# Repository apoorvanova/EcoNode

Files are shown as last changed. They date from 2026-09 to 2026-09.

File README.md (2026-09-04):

**EcoNode — Solar-Powered IoT Environmental Sensor Node**
A battery + solar-powered sensor node built around an ESP32-C3, designed and validated through schematic capture, power budget analysis, and firmware simulation.

**WHAT IS THIS PROJECT ABOUT?**
EcoNode wakes every 10 minutes, reads its environment sensor, advertises the reading over BLE, and returns to deep sleep — spending 99%+ of its life drawing only ~20µA. A 500mAh battery, topped up by a small solar cell, is estimated to run this indefinitely.

**PROJECT STATUS:**
This is a *design and simulation project*, not yet a fabricated physical board.
- ✅ Schematic: complete, fully wired, passes Electrical Rules Check with zero errors.
- ✅ Power budget: fully calculated (see table below).
- ✅ Firmware: written and logically verified against the schematic's pin map.
- ⚠️ Live simulation capture: attempted via both the Wokwi web simulator and a local VS Code + PlatformIO + Wokwi CLI pipeline; both were blocked by simulator-side tooling/server issues on the day of building this, rather than any issue in the code or wiring itself. The `/simulation` folder below contains the full working local-simulation setup for anyone who wants to run it themselves.
- 🔜 Next step: PCB layout and physical fabrication.

**REPO STRUCTURE:**

EcoNode/
├── README.md
├── schematic/
│   └── (KiCad project files + exported schematic PDF)
├── firmware/
│   ├── econode_firmware.ino            Firmware for the real BME280 sensor (matches the schematic)
│   ├── econode_wokwi_bmp280.ino        Wokwi-simulation variant (BMP280 - closest built-in part to BME280)
│   ├── econode_wokwi_bmp180.ino        Wokwi-simulation variant (BMP180 + Adafruit_BMP085 library)
│   └── econode_diagnostic_no_ble.ino   Stripped-down sensor-only test sketch, used for debugging
├── simulation/
│   ├── diagram.json                    Wokwi wiring diagram (ESP32-C3 + BMP180)
│   ├── platformio.ini                  PlatformIO build config for local compilation
│   └── wokwi.toml                      Points the Wokwi VS Code extension at the compiled firmware
├── docs/
│   ├── econode_extreme_detail_guide.md       Full click-by-click KiCad + Wokwi build walkthrough
│   ├── econode_annotated_guide.md            Component-by-component reasoning and datasheet references
│   ├── econode_net_reference.md              Complete pin/net map, organized by network
│   └── econode_from_scratch_by_network.md    Ground-up schematic build guide
└── images/
    ├── schematic.png       Exported schematic
    ├── erc_clean.png       Zero-error Electrical Rules Check confirmation
    └── firmware_code.png   Firmware source (in place of a live serial capture)

*A note on the sensor substitution:*
The schematic and BOM specify a **BME280** (temperature, humidity, pressure — the real, intended part). Neither the Wokwi web simulator nor its VS Code extension include a native BME280 model in their built-in parts library, so the firmware simulation substitutes the closest available part (BMP280, then BMP180 — same I2C interface, missing only the humidity reading). This is a simulation-environment limitation, not a design change — the schematic, wiring, and power budget all reflect the real BME280.

**POWER BUDGET SUMMARY:**

| Quantity | Value |
|---|---|
| Active current | 120 mA |
| Active duration/cycle | 3.2 s |
| Sleep current | 20 µA |
| Cycle period | 600 s |
| Average draw | ≈0.66 mAh/hr |
| Estimated battery life | ≈31.6 days (battery only), indefinite with solar |

**POWER DISTRIBUTION BY COMPONENT:**

| Component | Net | Active current | Sleep/idle current | Notes |
|---|---|---|---|---|
| ESP32-C3 (MCU + BLE) | 3V3 | ~120 mA (sensor read + BLE TX burst) | ~20 µA (deep sleep) | Dominates the active-phase budget; deep sleep is what makes the 31-day estimate possible |
| BME280 (sensor) | 3V3 | ~3.4 µA (forced/one-shot mode) | <1 µA (sleep mode) | Negligible compared to the MCU — barely affects the total |
| TPS63020 (regulator's own consumption) | VBAT → 3V3 | ~50 µA quiescent | ~50 µA quiescent (power-save mode via PS/SYNC) | This is the regulator's own overhead, separate from what it delivers downstream |
| TP4056 (charger) | SOLAR_IN → VBAT | up to ~234 mA (only while actively charging) | ~0 (idle once charge cycle completes) | Only draws from the solar input, not the battery — doesn't count against battery life |
| Status LED (D1) | LED_CTRL | ~4 mA (only during a brief firmware-triggered flash) | 0 mA (off otherwise) | Deliberately gated by firmware, not tied to always-on 3V3, to avoid wrecking the power budget |

**Why this table matters alongside the summary above:** the summary table tells you *how long the battery lasts*; this table tells you *why* — it makes clear that the ESP32's active burst is the single dominant term, and that keeping every other component's active time as short as possible (or firmware-gated, like the LED) is what protects the overall number.

**NEXT STEPS:**
- [ ] Resolve simulation tooling and capture live serial output
- [ ] PCB layout
- [ ] Fabrication and assembly
- [ ] Real-world battery life validation

**LICENSE:**
MIT — feel free to build on this.

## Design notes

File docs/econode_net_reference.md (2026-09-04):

# EcoNode — complete net reference (every pin, every net)

**The 4 nets in this design, and what's on each:**

## NET: GND (one single shared ground — every device ties here)
- Solar cell − terminal
- TP4056: `GND` pin, `EPAD` (thermal pad)
- Battery − terminal
- TPS63020: `GND` pin, `PGND` pin, `PAD` (thermal pad)
- Feedback resistor R2 (180kΩ) — the FB-to-GND leg
- TPS63020 `PS/SYNC` pin (tied low = power-save mode, this is intentional)
- ESP32-C3: `GND` pin (pin 9)
- BME280: `GND` pin (pin 1), `GND` pin (pin 7)
- 0.1µF decoupling cap at ESP32 — GND side
- 0.1µF decoupling cap at BME280 — GND side
- LED (D1) — cathode side

## NET: SOLAR_IN (raw ~5V from the panel, only exists on this one short run)
- Solar cell + terminal
- TP4056: `VCC` pin

## NET: VBAT (raw battery voltage, 3.0–4.2V depending on charge state)
- TP4056: `BAT` pin
- Battery + terminal
- TPS63020: `VIN` pin, `VINA` pin
- 10µF caps at VIN (both of them)
- 1µF cap at VINA

## NET: 3V3 (regulated, stable output — everything downstream lives here)
- TPS63020: `VOUT` pin
- 10µF cap at VOUT
- Feedback resistor R1 (1MΩ) — the VOUT-to-FB leg (goes to the FB net, not directly to 3V3 — see below)
- ESP32-C3: `3V3` pin (pin 1)
- 0.1µF decoupling cap at ESP32 — 3V3 side
- BME280: `VDD` pin, `VDDIO` pin, `CSB` pin (tying CSB high selects I2C mode)
- 0.1µF decoupling cap at BME280 — 3V3 side
- LED resistor R3 (330Ω) — the side NOT going to the LED (i.e., R3 connects 3V3... actually see note below)

## NET: FB (a small, separate net — just the midpoint of the divider, only 3 things touch it)
- TPS63020: `FB` pin
- R1 (1MΩ) — one leg
- R2 (180kΩ) — one leg
(R1's other leg is on 3V3, R2's other leg is on GND — this is what makes it a divider)

## NET: SDA (just 2 things)
- ESP32-C3: `IO08` pin
- BME280: `SDI` pin

## NET: SCL (just 2 things)
- ESP32-C3: `IO09` pin
- BME280: `SCK` pin

## NET: LED_CTRL (a spare GPIO controlling the status LED — NOT the same as 3V3)
- ESP32-C3: a spare GPIO (your image shows it near pin `IO16`)
- R3 (330Ω) — one leg
- (R3's other leg → LED anode → LED cathode → GND, completing the loop back to the GND net)

This is a firmware-controlled LED (correct, matches the earlier note about not wanting it hardwired always-on) — the firmware sets this GPIO high briefly during a wake cycle to flash it, rather than leaving it permanently lit and burning battery.

## NET: EN (TPS63020's enable pin) — ⚠️ STILL NEEDS FIXING

This should be its own net, tied to **3V3 or VBAT** (either works — active-high enable) — **not tied to GND.**

Looking at your latest screenshot, the wire path connecting `EN`, `PS/SYNC`, and `GND` at the bottom of the TPS63020 still appears to loop back into the same rail as the TP4056's ground area — meaning **EN is still on the GND net, same issue as last time.** If EN stays on GND, the regulator will never turn on and nothing downstream gets power, no matter how correct everything else is.

**Fix:** disconnect EN from that shared bottom rail, and instead run a short wire (or net label) from EN directly to the `3V3` net or the `VBAT` net. PS/SYNC can stay on GND — that part's fine and intentional.

---

## Pins that are genuinely fine to leave unconnected — but need an explicit no-connect flag

These pins are optional status/feature pins on the TP4056 that this design isn't using. Leaving them electrically floating is fine functionally, but KiCad's ERC will keep flagging them with warning markers until you explicitly tell it "yes, I meant to leave this floating" by pressing **Q** on each pin (or clicking it and adding a no-connect flag from the toolbar):

- TP4056 `CE` — **check your specific TP4056 variant's datasheet first**: some versions need CE actively tied low to enable charging rather than left floating. Don't assume it's safe to leave open without checking.
- TP4056 `CHRG` — status output (LED driver for "currently charging"), fine to leave unconnected if you don't want a charge-indicator LED.
- TP4056 `STDBY` — status output ("charge complete"), same — fine to leave unconnected if unused.
- TP4056 `TEMP` — **also check the datasheet**: many TP4056 variants require TEMP tied to GND (or through a specific resistor) to *disable* the temperature-monitoring safety feature; leaving it truly floating can sometimes make the IC think there's a fault and refuse to charge at all. This one is worth confirming rather than guessing.
- TP4056 `PROG` — this one is NOT optional, it needs a resistor to GND to set charge current (discussed earlier, ~4kΩ for a gentle charge rate). Confirm this resistor is actually present in your schematic — I couldn't fully confirm it from the image.
- TPS63020 `PG` — fine to tie to GND as you have it (just means you're not using the power-good monitoring feature, harmless either way).

---

## Quick self-check before your next screenshot

1. Click on the EN pin of the TPS63020 in KiCad and check the net name shown in the status bar / properties — it should say `3V3` or `VBAT`, not `GND`.
2. Run ERC (**Inspect → Electrical Rules Checker**) and read every remaining warning individually rather than skimming — for each one, decide "this needs a wire" or "this needs a no-connect flag," don't leave any unresolved.
3. Double check the TP4056 datasheet specifically for what CE and TEMP need — I flagged these as uncertain because I genuinely can't confirm the exact required state for your specific part variant without seeing its datasheet directly.

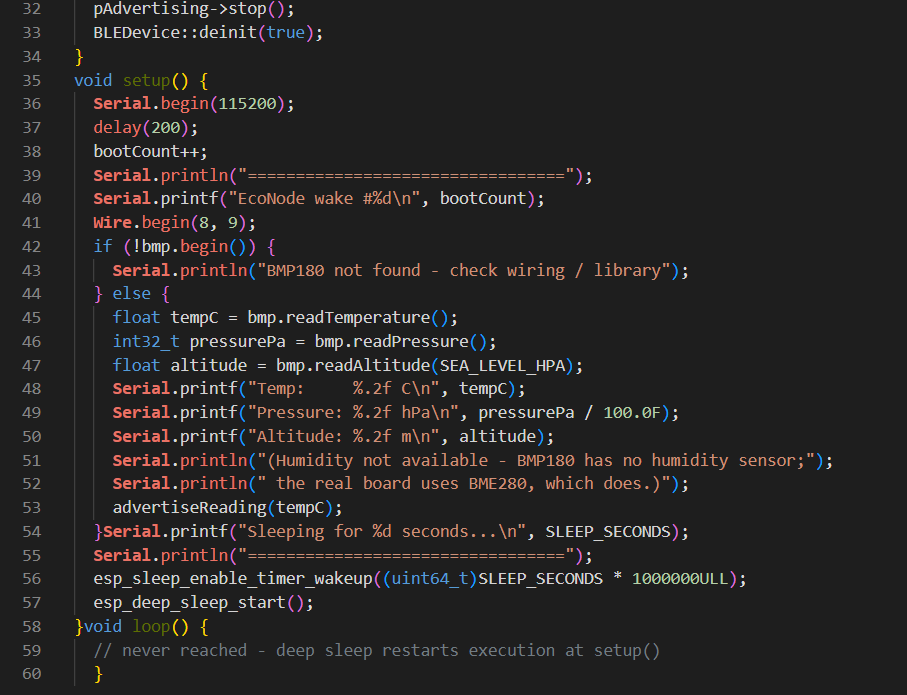
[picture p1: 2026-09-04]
images/code_2.png

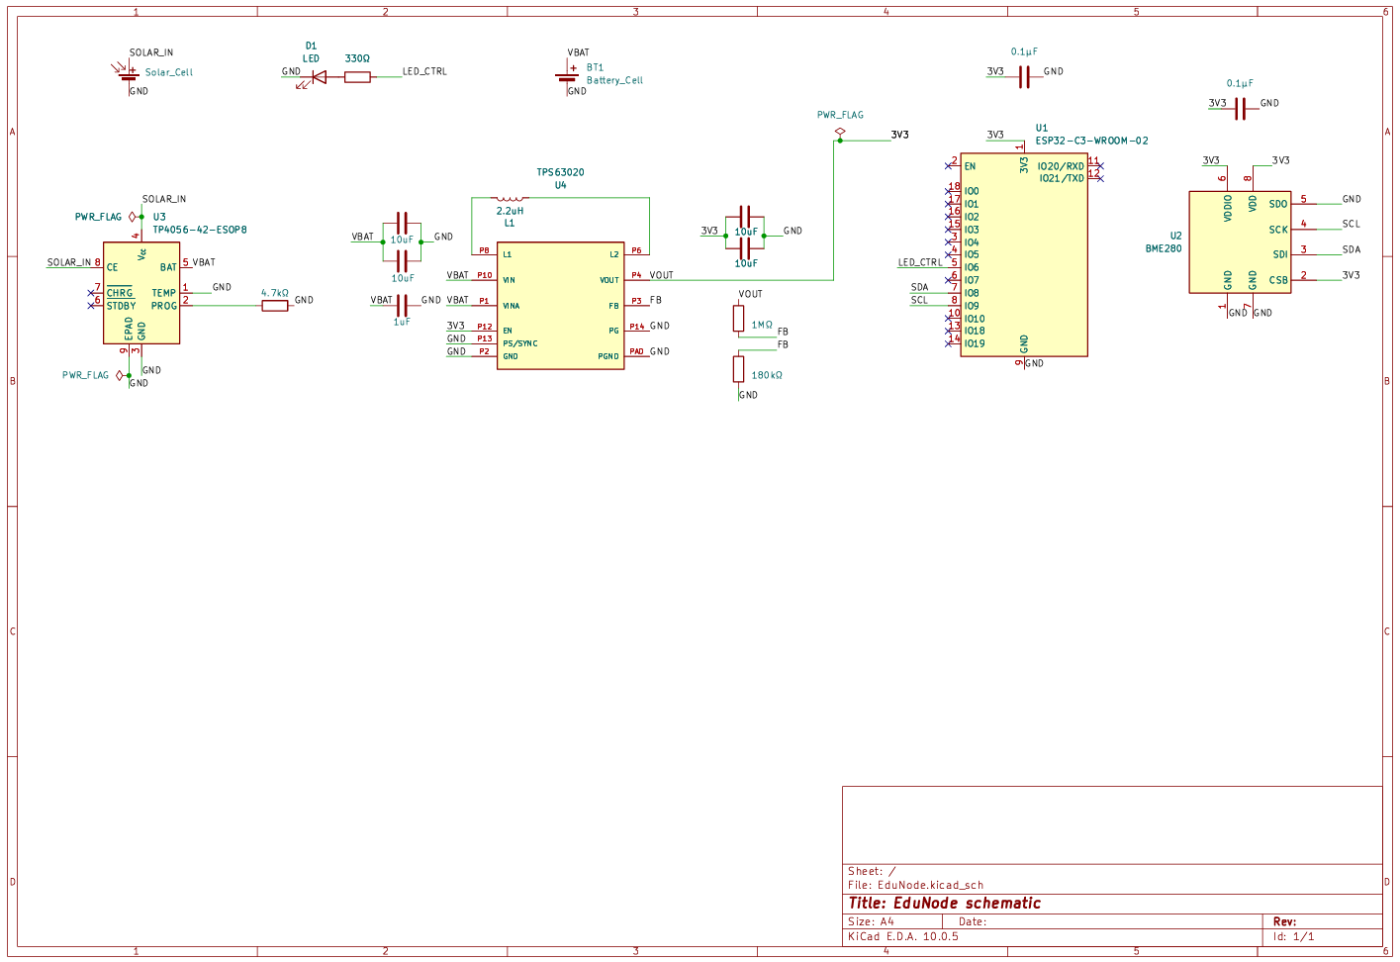
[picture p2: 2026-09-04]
images/EduNode_sch.png

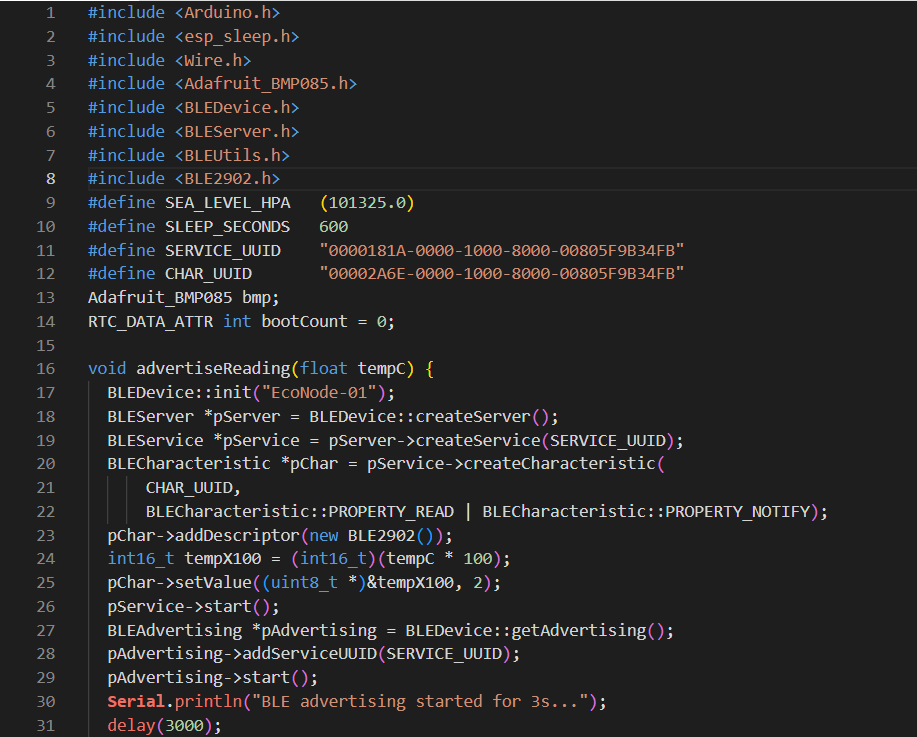
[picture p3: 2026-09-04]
images/code_1.png

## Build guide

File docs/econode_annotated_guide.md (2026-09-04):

# EcoNode — annotated build guide (the "why" behind every choice)

This follows the same part structure as the extreme-detail guide, but stops at every component and wire to explain *why that specific device, why that specific value, why that specific connection* — tied back to the five-stage theory pipeline (harvest → charge → store → regulate → duty-cycle).

---

## Part B — Why these specific parts (not other ones)

### ESP32-C3-WROOM-02 (the MCU)
**What it is:** A single-core RISC-V microcontroller module with built-in Bluetooth Low Energy, integrated flash memory, and an onboard antenna — already assembled onto a small PCB module rather than a bare chip.

**Why this one, specifically:**
- It has a genuinely low deep-sleep current (~20µA) — this is the number your entire 31-day battery life calculation depends on (Stage 5 theory). Pick a chip with worse sleep current and the whole story falls apart.
- BLE is built-in — no separate radio chip needed, which means fewer parts, fewer failure points, and a simpler schematic.
- It's a *module*, not a bare IC — meaning someone already solved the hard RF antenna design for you. Antenna design is genuinely advanced (see the PCB section below); using a pre-certified module sidesteps that entirely.
- Massive Arduino/Wokwi ecosystem support, which is why you can actually simulate it today.

**What a "more correct" industry choice would be:** Nordic's nRF52 series is the actual industry standard for battery/wearable BLE devices — even lower sleep current, purpose-built for exactly this use case. ESP32-C3 is chosen here for accessibility (better beginner tooling), not because it's the objectively best chip. Worth knowing this distinction if it comes up in an interview.

### BME280 (the sensor)
**Why this one, not a DHT22 or BMP280:** The DHT22 (a common cheaper alternative) uses a slow single-wire protocol and has notably lower accuracy. The BMP280 only measures temperature and pressure — no humidity. The BME280 measures all three (temp, humidity, pressure), talks over I2C (Stage 5's "SDA/SCL" wiring), and — critically for your power budget — draws as little as ~3.4µA in its low-power "forced mode," meaning it barely dents your sleep-current number.

### TP4056 (the charge controller)
**Why this one:** It's the most common, cheapest, best-documented single-cell Li-ion charger IC that exists — this matters because as a first-timer, you want a part with abundant reference designs to check your work against. It implements exactly the CC-then-CV charging behavior from Stage 2 theory: it holds a constant current until the cell hits 4.2V, then holds constant voltage while tapering current.

**Why the charge current value matters:** The IC's charge current is set by a resistor on its `PROG` pin, using the formula `I_charge = 1000mA / R_prog(kΩ)`. For a 500mAh cell, you want roughly 0.2–0.5C (100–250mA) — so you'd pick R_prog around 4kΩ (giving ~250mA) or higher for a gentler charge. Since your solar panel can only supply ~60–100mA anyway, the actual charge current will be limited by the panel, not the resistor — but you still set R_prog sensibly in case someone later charges it over USB instead.

**What a "more correct" industry choice would be:** A dedicated energy-harvesting IC like the TI BQ25570 does MPPT (maximum power point tracking) — it actively adjusts to pull the *most* power out of a small solar cell as light conditions change, rather than just accepting whatever the TP4056 is fed. It's the right part for a genuinely optimized product, but it's also a much harder chip to design around as a first PCB. TP4056 is the beginner-appropriate choice; BQ25570 is the "if you keep going in this direction" upgrade.

### TPS63020 (the buck-boost regulator) — and the missing inductor
**Why buck-boost and not a plain LDO:** covered in the theory section — a Li-ion cell swings from 4.2V down to 3.0V, and a plain LDO can't hold 3.3V once the input drops below ~4.4V. A buck-boost converter steps the voltage *up or down* as needed to hold a steady 3.3V across that whole range.

**The part I missed earlier:** Buck-boost (and all switching) regulators work by rapidly switching current through an **inductor** to store and transfer energy — this isn't optional, it's how the topology fundamentally works. You need to add:
- One inductor (check the TPS63020 datasheet's "typical application circuit" — it'll specify a value, commonly around 2.2µH) connected between the two switch-node pins (`L1` and `L2` on the IC).
- A feedback resistor divider from `VOUT` to the `FB` pin, sized per the datasheet formula, to tell the IC "you're at 3.3V, stop adjusting."

Go find that typical application diagram in the datasheet before you finalize your schematic — this is the one part of the design where copying the datasheet's reference circuit almost exactly is the right move, not a shortcut. Every analog/power engineer does this; it's normal practice, not cheating.

### Battery cell — 3.7V, 500mAh
**Why 500mAh specifically:** It's a size/runtime tradeoff. A 500mAh cell is physically small (roughly the size of a AAA battery in a pouch form factor), keeps the whole device pocket-sized, and — per your Stage 5 math — still gives ~31 days of runtime at this duty cycle. Going bigger (1000mAh+) would extend runtime further but adds bulk and cost for a benefit you don't really need once solar is factored in.

### Solar cell — ~5V, 60–100mA
**Why this voltage/current range:** The TP4056 wants an input voltage a bit above the battery's 4.2V max (typically 4.5–5.5V) to charge effectively — a 5V panel matches this directly. The current rating doesn't need to be large because you calculated the device only needs 0.66mAh/hour on average — even a weak, partially-shaded panel can outrun that.

### Decoupling capacitors — why 0.1µF near ICs, 10µF at the regulator
- **0.1µF ceramic caps** placed right next to every IC's power pin filter out high-frequency noise and respond instantly to sudden current demand. This matters most right at the ESP32: when it wakes from deep sleep, current jumps from 20µA to 120mA almost instantaneously. Without a cap sitting right there to supply that initial surge locally, the voltage rail can sag enough to brown out the chip mid-wake — which would be a maddening, hard-to-diagnose bug.
- **10µF bulk caps at the TPS63020's input and output** exist for the same reason but at a larger scale — they're a local reservoir of charge that absorbs the bigger current swings a switching regulator itself creates, and datasheet reference designs specifically call for them near the regulator to keep its internal feedback loop stable (without them, some switching regulators can oscillate).

### Status LED + 330Ω resistor
**Why 330Ω:** Standard LED current-limiting formula: `R = (V_supply − V_LED) / I_desired`. With a 3.3V rail, a ~2V LED forward voltage, and a target of ~4mA (dim but visible, power-conscious), you get `(3.3−2.0)/0.004 ≈ 325Ω` → round to the nearest standard value, 330Ω.

**A real design tension worth noting:** an LED left continuously on would burn through your power budget fast — 4mA constantly is actually more current than your entire sleep-phase average draw. In a real product you'd flash it briefly during the wake cycle only, controlled in firmware, not leave it lit.

---

## Part D — Why these specific wires (tied back to the theory pipeline)

| Wire/net | Why it exists |
|---|---|
| Solar+/− → TP4056 IN+/IN− | Stage 1 → Stage 2 handoff: raw harvested power enters the charge controller's designated input pins, matching the IC's expected input voltage range. |
| TP4056 BAT+/− → Battery | This is the CC/CV-regulated output of Stage 2 feeding directly into Stage 3 storage — the IC is doing the smart charging math here, not you. |
| Battery+ → TPS63020 VIN | Stage 3 → Stage 4: the raw, sagging 3.0–4.2V battery voltage enters the regulator that will stabilize it. |
| TPS63020 VOUT (3V3) with 10µF cap | Stage 4's output: a stabilized rail. The cap right here is non-negotiable per the datasheet — it's part of making the switching regulator stable, not just "good practice." |
| 3V3 → ESP32 3V3 pin, with 0.1µF cap | Feeds Stage 5's compute. The cap specifically protects against the wake-current surge discussed above. |
| 3V3 → BME280 VCC, with 0.1µF cap | Same reasoning, smaller scale — the sensor's current draw is tiny but still benefits from local filtering. |
| GPIO8 (SDA) / GPIO9 (SCL) → BME280 | Correction from an earlier version of this guide: GPIO21/22 is the *classic ESP32's* default I2C pair, not the ESP32-C3's — on the C3, GPIO21 is TXD and is already needed for serial debug output. GPIO8/9 are genuinely free pins on the C3 with no conflicts, which is why the firmware now calls `Wire.begin(8, 9)` explicitly rather than relying on a default. |
| GPIO2 → resistor → LED → GND | GPIO2 is chosen because it's a free pin on the ESP32-C3 that isn't one of the "strapping pins" (pins like GPIO8/9 that must be in a specific state at boot to control boot mode) — using a strapping pin for something like an LED can accidentally prevent the chip from booting correctly. |
| No-connect flags on unused ESP32 pins | Not a "why" about circuit function — this is about telling KiCad's ERC "I deliberately left this pin unused," so it doesn't flag a false error. Also forces you to actually look at every pin and consciously decide, rather than skip pins by accident. |

---

## Part E — What ERC actually checks (and what it doesn't)

Worth being clear-eyed about this: ERC only checks *electrical connectivity rules* — unconnected pins, conflicting outputs tied together, missing power flags. It has no idea whether your TPS63020 feedback resistor values are correct, whether your inductor value matches the datasheet, or whether your circuit will actually work. A schematic can pass ERC with zero errors and still be functionally wrong. ERC is a spelling-checker, not a fact-checker — the datasheet typical application circuit is your fact-checker.

---

## Part F — Why these specific footprints (SOT23, 0603)

This choice is really about matching the design to *your* fabrication capability, not just electrical correctness:
- **SOT23-5/SOT23-6 packages** (for TP4056, TPS63020) are chosen because they're hand-solderable with a decent soldering iron and some patience — the alternative, QFN packages, have pads hidden underneath the chip and genuinely require hot-air rework or a reflow oven, which is out of reach for a first build.
- **0603 passives** (resistors/caps) are a deliberate middle ground: 0805 is easier still but looks noticeably bulkier and less "modern" in photos; 0402 is small enough that hand-soldering without a microscope becomes genuinely frustrating. 0603 is the sweet spot most hobbyists settle on.

---

## Part H — Is the PCB layout too tough? An honest answer

**Short answer: moderately tough, but worth attempting — with the right expectations.**

What makes it *not* too tough:
- You're not designing an antenna (the ESP32 module has one built-in) — RF layout, the genuinely hard part of PCB design, is already solved for you.
- ~15–20 components on a simple 2-layer board is a completely standard "first board" scope. Plenty of first-timers do this.
- You don't need it to be perfect — even a rough, autorouted board that you never fabricate still demonstrates real competence in a screenshot.

What makes it genuinely harder than a trivial board (be aware of these, don't skip them):
- **The switching regulator needs care.** The TPS63020's inductor loop (the path current takes through the inductor and switch pins) should be kept short and the traces reasonably wide — long, thin traces here can cause real-world instability. For a *simulation-only, never-fabricated* board this doesn't actually matter functionally, but doing it right is the actual skill being demonstrated.
- **Keep the sensor away from the regulator.** The BME280 is a sensitive analog sensor; the TPS63020 is a noisy switching regulator. Standard practice is physical separation — place the sensor as far from the regulator's switch node as the board allows, and keep it on the schematic's "quiet" side.
- **Datasheet typical application circuit is your reference**, especially for the TPS63020's inductor and feedback network — don't wing these values, copy them from the datasheet and just verify they make sense for a 3.3V output.

**My honest recommendation:** try it. Budget 2–3 hours rather than the 1–2 in the original guide, actually pull the TPS63020 datasheet's typical application page before you place its surrounding parts, and don't stress about getting the autorouter's result perfect — the point is demonstrating you understand the process, not shipping a production-ready board.

---

## Part I — Why this specific BLE setup in firmware

The service UUID used in the firmware (`0000181A-...`) isn't arbitrary — it's the **official Bluetooth SIG-assigned UUID for "Environmental Sensing Service."** Using a standard, registered UUID (instead of a random one you made up) means any generic BLE scanner app on a phone would recognize your device as an environmental sensor without needing custom app code — this is how real commercial BLE devices behave, and it's a small detail that signals you understand the BLE ecosystem beyond just "make two devices talk."

---

**Bottom line across every part:** almost every "why" above comes back to the same handful of ideas from the theory pipeline — respect the battery's real voltage range (Stage 3/4), protect against current surges at wake (Stage 5), and choose parts/packages that match what you can actually build and verify at your current skill level. That consistency is exactly what you'd want to be able to explain if someone grilled you on this project in an interview.

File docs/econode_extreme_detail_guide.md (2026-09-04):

# EcoNode — extreme-detail build guide

This assumes you have never opened KiCad. Every step names the exact menu, panel, or keyboard shortcut.

---

## Part A — Install and set up

1. Go to kicad.org/download, download **KiCad 8.x** for your OS, install with defaults.
2. Open KiCad. Click **File → New Project**. Name it `EcoNode`, pick a folder. This creates a `.kicad_pro` file plus an empty schematic and PCB.
3. Double-click the schematic icon (`.kicad_sch`) in the project window, or click **Open Schematic Editor** — this is where you'll spend most of your day.
4. In the Schematic Editor, go to **Preferences → Manage Symbol Libraries** and confirm the default KiCad libraries are checked (they are by default on a fresh install) — you need `Device`, `MCU_Espressif`, `Battery_Management`, `Regulator_Linear`, `Connector`.

---

## Part B — Place every symbol (do this before wiring anything)

For each part below: press **A** (or click the symbol icon in the right toolbar) to open the symbol chooser, type the search term, double-click the match, click on the canvas to place it, press **Escape** to stop placing copies.

1. Search `ESP32-C3-WROOM-02` → place near the center-left of the canvas.
2. Search `BME280` → place to the right of the ESP32.
3. Search `TP4056` → place on the far left (this is your power input stage).
4. Search `TPS63020` (buck-boost regulator — see Stage 4 theory above for why this replaces a plain LDO) → place between TP4056 and the ESP32.
5. **Search `L` (inductor)** → place one between the TPS63020's two switch-node pins (usually labeled `L1`/`L2` or `SW1`/`SW2` on the symbol). Buck-boost regulators work by switching current through an inductor — this part is not optional, the IC will not function without it. Check the TPS63020 datasheet's "typical application circuit" for the exact value; it's commonly around 2.2µH.
6. Place **2x resistors** for the feedback divider (search `R`) between `VOUT` and the `FB` pin — again, get the exact values from the datasheet's typical application circuit, since they set your 3.3V output.
7. Search `Battery_Cell` → place below the TP4056, this represents your Li-ion cell.
8. Search `Solar_Cell` (if not found, use a second `Battery_Cell` and rename it "Solar" in Part C) → place to the left of the TP4056.
9. Place **6x capacitor** symbols: search `C`, place 4x near the ESP32 and TPS63020 power pins (0.1µF decoupling), 2x near the TPS63020 input/output (10µF bulk).
10. Place **1x LED** and **1x resistor** (search `LED`, then `R`) for a status indicator — optional but looks complete.
11. Save with **Ctrl+S**.

---

## Part C — Rename and set values

1. Click each capacitor, press **E** (edit properties), set the Value field: `0.1uF` for decoupling caps, `10uF` for bulk caps.
2. Click the resistor, set Value to `330`.
3. Click each part and check the **Reference** field auto-numbered (C1, C2, R1, etc.) — leave as-is.
4. If you used a generic Battery_Cell for the solar input, click it, press **E**, change the Value field to `Solar 5V`.

---

## Part D — Wire everything (the actual circuit)

Use **W** to draw a wire between two pins. For longer/cleaner schematics, use **net labels** instead of drawing every wire physically: press **L**, type a name (e.g. `VBAT`, `3V3`, `GND`, `SDA`, `SCL`), place it at a pin — any two pins with the same label are electrically connected even without a drawn wire.

Wire in this exact order:

1. **Solar → TP4056**: Solar+ pin → TP4056 `IN+` pin. Solar− → TP4056 `IN-`.
2. **TP4056 → Battery**: TP4056 `BAT+` → Battery+ terminal. TP4056 `BAT-` → GND net label.
3. **Battery → TPS63020 input**: Battery+ → TPS63020 `VIN`. GND → GND net label (same net as above).
4. **TPS63020 switch node → inductor**: wire the inductor between the TPS63020's two switch pins (check the datasheet pinout — commonly `L1` and `L2`, or `SW1`/`SW2`). Keep this wire short in your head for now; on the PCB (Part H) this loop should be kept physically short and traces reasonably wide.
5. **TPS63020 output → power rail**: TPS63020 `VOUT` → net label `3V3`. Place a 10µF cap between `3V3` and `GND` right at this pin (bulk decoupling — required for loop stability, not optional).
6. **Feedback divider**: wire the two feedback resistors from Part B in series between `VOUT` and `GND`, with the midpoint connected to the TPS63020's `FB` pin. This tells the IC what voltage it's actually outputting so it can regulate to 3.3V — use the exact resistor values from the datasheet's typical application circuit.
7. **3V3 rail → ESP32**: ESP32 `3V3` pin → net label `3V3`. ESP32 `GND` pin → net label `GND`. Place a 0.1µF cap between them, close to the pin.
8. **3V3 rail → BME280**: BME280 `VCC` → net label `3V3`. BME280 `GND` → net label `GND`. Place a 0.1µF cap between them.
9. **I2C bus**: ESP32-C3 `GPIO8` → net label `SDA` → also place `SDA` label at BME280 `SDI` pin. ESP32-C3 `GPIO9` → net label `SCL` → also place at BME280 `SCK` pin. (Note: GPIO21/22 is the classic-ESP32 default and does not apply to the C3 — GPIO21 on the C3 is TXD, already needed for serial debug output.) Also wire BME280 `CSB` → `3V3` (selects I2C mode over SPI), `SDO` → `GND` (sets I2C address to 0x76), and `VDDIO` → `3V3`.
10. **Status LED**: ESP32 any spare GPIO (e.g. `GPIO2`, avoid strapping pins like GPIO8/9) → resistor → LED anode. LED cathode → `GND`.
11. Every unused pin on the ESP32 module (there will be several) needs a **no-connect flag**: click the pin, press **Q**, or use the no-connect symbol from the toolbar (looks like an X). This is required to pass ERC cleanly.

---

## Part E — Run Electrical Rules Check (ERC)

1. **Inspect menu → Electrical Rules Checker → Run ERC**.
2. Read every warning. Common ones you'll see as a first-timer:
   - "Pin not connected" → you missed a no-connect flag on Part D step 9, or a genuine wiring gap.
   - "Multiple pins in net not driven" → usually means a net label typo (e.g. `GND` vs `Gnd`, KiCad is case-sensitive) — check every net label matches exactly.
3. Fix everything until ERC shows **0 errors**. Warnings about unused power flags on a first schematic are usually fine to leave.

---

## Part F — Assign footprints (needed only if you're doing PCB layout)

1. **Tools → Assign Footprints**.
2. For each part, pick a footprint from the library on the left — ESP32 module footprints are under `RF_Module`, TP4056 and TPS63020 are usually SOT23 packages under `Package_TO_SOT_SMD`, capacitors/resistors under `Capacitor_SMD` / `Resistor_SMD` (pick `C_0603` / `R_0603`).
3. Click **Apply, Save Schematic & Continue**.

---

## Part G — Export your LinkedIn screenshot

1. **File → Plot**, output format **PDF**, plot the schematic sheet.
2. Open the PDF, take a clean screenshot (or export directly as PNG via a screenshot tool) — this is your first LinkedIn image.

---

## Part H — Optional: PCB layout

1. **Tools → Update PCB from Schematic**, click **Update PCB**.
2. In the PCB Editor, you'll see all footprints stacked in one spot — drag them apart into a rough layout: power components (TP4056, TPS63020, inductor, battery connector) on one side, ESP32 + BME280 on the other. Two things worth doing deliberately here: keep the TPS63020-to-inductor loop short (this is the "noisy" switching loop), and keep the BME280 physically as far from the TPS63020 as the board allows, since it's a sensitive analog sensor sitting near a switching regulator.
3. **Route → Autorouter** isn't built into KiCad 8 directly — instead, manually route the 4–6 simple traces yourself using the **X** (route) tool, or export a `.dsn` file (**File → Export → Specctra DSN**) and run it through the free tool at freerouting.org, then import the routed `.ses` file back.
4. **View → 3D Viewer** (or press **Alt+3**) for a 3D render — screenshot this for LinkedIn image #2.

---

## Part I — Wokwi firmware simulation

1. Go to wokwi.com, sign in (free), **New Project → ESP32**.
2. In the parts panel (bottom left, `+` icon), search `BME280`, add it. Wire it: `VCC → 3V3`, `GND → GND`, `SCL → D22`, `SDA → D21` (drag between pins on the diagram).
3. Open `sketch.ino` in the code panel, delete the default content, paste the firmware from `econode_firmware.ino` (already generated for you).
4. Click the green **Play** button. Watch the **Serial Monitor** panel — you should see temperature/humidity/pressure print, then "Sleeping for 600 seconds," then the simulation pauses (deep sleep).
5. Screenshot the serial output — this is your LinkedIn image #3, and the strongest proof that this isn't just a static schematic.

---

## Part J — Power budget worksheet (for your post)

Fill in with your actual measured/simulated numbers if they differ from the estimates:

| Quantity | Value | Source |
|---|---|---|
| Active current | 120 mA | ESP32-C3 datasheet, BLE TX burst |
| Active duration per cycle | 3.2 s | sensor read (~0.2s) + BLE advertise (3s) |
| Sleep current | 20 µA | ESP32-C3 datasheet, deep sleep |
| Cycle period | 600 s | your firmware's `SLEEP_SECONDS` |
| Charge per cycle | ≈ 0.110 mAh | (120mA × 3.2/3600) + (0.02mA × 596.8/3600) |
| Average draw | ≈ 0.66 mAh/hr | 6 cycles/hour × 0.110 mAh |
| Battery capacity | 500 mAh | cell datasheet |
| Estimated battery life | ≈ 31.6 days | 500 ÷ 0.66 |

---

You now have three screenshots (schematic, 3D PCB render if you did Part H, Wokwi serial output) and one table. That's the full post.

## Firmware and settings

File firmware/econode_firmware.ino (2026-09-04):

/*
  EcoNode - Solar-powered BLE environmental sensor node
  Simulated in Wokwi: ESP32 + BME280

  Wake -> read sensor -> advertise over BLE -> deep sleep -> repeat.
  This is the core power-saving pattern used in real battery/solar IoT nodes:
  the MCU spends >99% of its life in deep sleep (~20uA) and only wakes
  briefly (~200ms, ~120mA) to sense and transmit.

  Wokwi setup:
    1. New project -> "ESP32-C3" (not plain "ESP32" - different chip, different pins)
    2. Add a "BME280" part from the parts panel, wire:
         VCC -> 3V3, GND -> GND, SCL -> GPIO9, SDA -> GPIO8
    3. Paste this sketch, hit play.
*/

#include <Wire.h>
#include <Adafruit_Sensor.h>
#include <Adafruit_BME280.h>
#include <BLEDevice.h>
#include <BLEServer.h>
#include <BLEUtils.h>
#include <BLE2902.h>

#define SEA_LEVEL_HPA   (1013.25)
#define SLEEP_SECONDS   600        // 10 minute duty cycle
#define SERVICE_UUID    "0000181A-0000-1000-8000-00805F9B34FB" // BLE Environmental Sensing
#define CHAR_UUID       "00002A6E-0000-1000-8000-00805F9B34FB" // Temperature characteristic

Adafruit_BME280 bme;
RTC_DATA_ATTR int bootCount = 0;   // survives deep sleep, useful for battery-life logging

void advertiseReading(float tempC, float humidity, float pressureHpa) {
  BLEDevice::init("EcoNode-01");
  BLEServer *pServer = BLEDevice::createServer();
  BLEService *pService = pServer->createService(SERVICE_UUID);

  BLECharacteristic *pChar = pService->createCharacteristic(
      CHAR_UUID,
      BLECharacteristic::PROPERTY_READ | BLECharacteristic::PROPERTY_NOTIFY);
  pChar->addDescriptor(new BLE2902());

  int16_t tempX100 = (int16_t)(tempC * 100);
  pChar->setValue((uint8_t *)&tempX100, 2);

  pService->start();
  BLEAdvertising *pAdvertising = BLEDevice::getAdvertising();
  pAdvertising->addServiceUUID(SERVICE_UUID);
  pAdvertising->start();

  Serial.println("BLE advertising started for 3s...");
  delay(3000);   // real node would advertise briefly, then stop to save power
  pAdvertising->stop();
  BLEDevice::deinit(true);
}

void setup() {
  Serial.begin(115200);
  delay(200);
  bootCount++;

  Serial.println("=================================");
  Serial.printf("EcoNode wake #%d\n", bootCount);

  Wire.begin(8, 9);   // SDA = GPIO8, SCL = GPIO9 on ESP32-C3 (GPIO21/22 is the classic-ESP32 default, not valid here)
  if (!bme.begin(0x76)) {
    Serial.println("BME280 not found - check wiring");
  } else {
    float tempC     = bme.readTemperature();
    float pressure  = bme.readPressure() / 100.0F;
    float humidity  = bme.readHumidity();
    float altitude  = bme.readAltitude(SEA_LEVEL_HPA);

    Serial.printf("Temp:     %.2f C\n", tempC);
    Serial.printf("Humidity: %.2f %%\n", humidity);
    Serial.printf("Pressure: %.2f hPa\n", pressure);
    Serial.printf("Altitude: %.2f m\n", altitude);

    advertiseReading(tempC, humidity, pressure);
  }

  Serial.printf("Sleeping for %d seconds...\n", SLEEP_SECONDS);
  Serial.println("=================================");
  esp_sleep_enable_timer_wakeup((uint64_t)SLEEP_SECONDS * 1000000ULL);
  esp_deep_sleep_start();
}

void loop() {
  // never reached - deep sleep restarts execution at setup()
}

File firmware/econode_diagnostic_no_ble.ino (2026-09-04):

/*
  EcoNode - DIAGNOSTIC VERSION (no BLE)
  Use this to test whether the BMP180 sensor and library work correctly
  on their own, before adding BLE back in. If this runs fine and prints
  readings, the problem is in the BLE section, not the sensor.

  Wokwi setup: same as before - ESP32-C3, BMP180 part, Adafruit BMP085
  Library added via Library Manager.
*/

#include <Wire.h>
#include <Adafruit_BMP085.h>

Adafruit_BMP085 bmp;

void setup() {
  Serial.begin(115200);
  delay(500);
  Serial.println("=== EcoNode diagnostic start ===");

  Wire.begin(8, 9);

  if (!bmp.begin()) {
    Serial.println("BMP180 not found - check wiring / library");
  } else {
    Serial.println("BMP180 found successfully!");
    float tempC = bmp.readTemperature();
    Serial.printf("Temp: %.2f C\n", tempC);
  }
}

void loop() {
  Serial.println("Loop running - sketch loaded fine.");
  delay(2000);
}
